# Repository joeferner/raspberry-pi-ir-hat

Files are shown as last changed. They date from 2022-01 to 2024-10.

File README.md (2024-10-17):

# Environment variables

- `LOG_LEVEL`
- `MQTT_ID` (default: `pi-ir`)
- `MQTT_HOST`
- `MQTT_PORT` (default: 1883)
- `MQTT_TOPIC_PREFIX` (default: `home/ir`)

# MQTT

- `${MQTT_TOPIC_PREFIX}/receive/raw` - raw IR data (see LircEvent)
- `${MQTT_TOPIC_PREFIX}/receive/decode` - decoded IR data (see DecodeResult)

# Setup Raspberry Pi

1. Install rpi-imager locally
1. Edit Settings
   - hostname: ir
   - set username/password
   - (optional) configure wireless lan
   - set locale settings
   - enable ssh
1. Start the Raspberry Pi, open a command prompt and `ping ir.local`
1. Open a terminal

        ssh <username>@ir.local
        sudo apt update
        sudo apt -y install git
        # copy id_rsa from host computer
        chmod 600 ~/.ssh/id_rsa
        ssh-keygen -p -f ~/.ssh/id_rsa # remove password
        git clone git@github.com:joeferner/raspberry-pi-ir-hat.git
        ./raspberry-pi-ir-hat/scripts/raspberry-pi-setup.sh

# Raspberry Pi development

1. Install "Remote Development" extension pack for VSCode.
1. Connect VSCode via ssh (Ctrl+Shift+P -> Remote-SSH: Connect to Host...) `<username>@ir.local`
1. Stop service `sudo systemctl stop raspberry-pi-ir-hat-network-bridge`
1. Run `RUST_BACKTRACE=1 LOG_LEVEL=debug cargo run`

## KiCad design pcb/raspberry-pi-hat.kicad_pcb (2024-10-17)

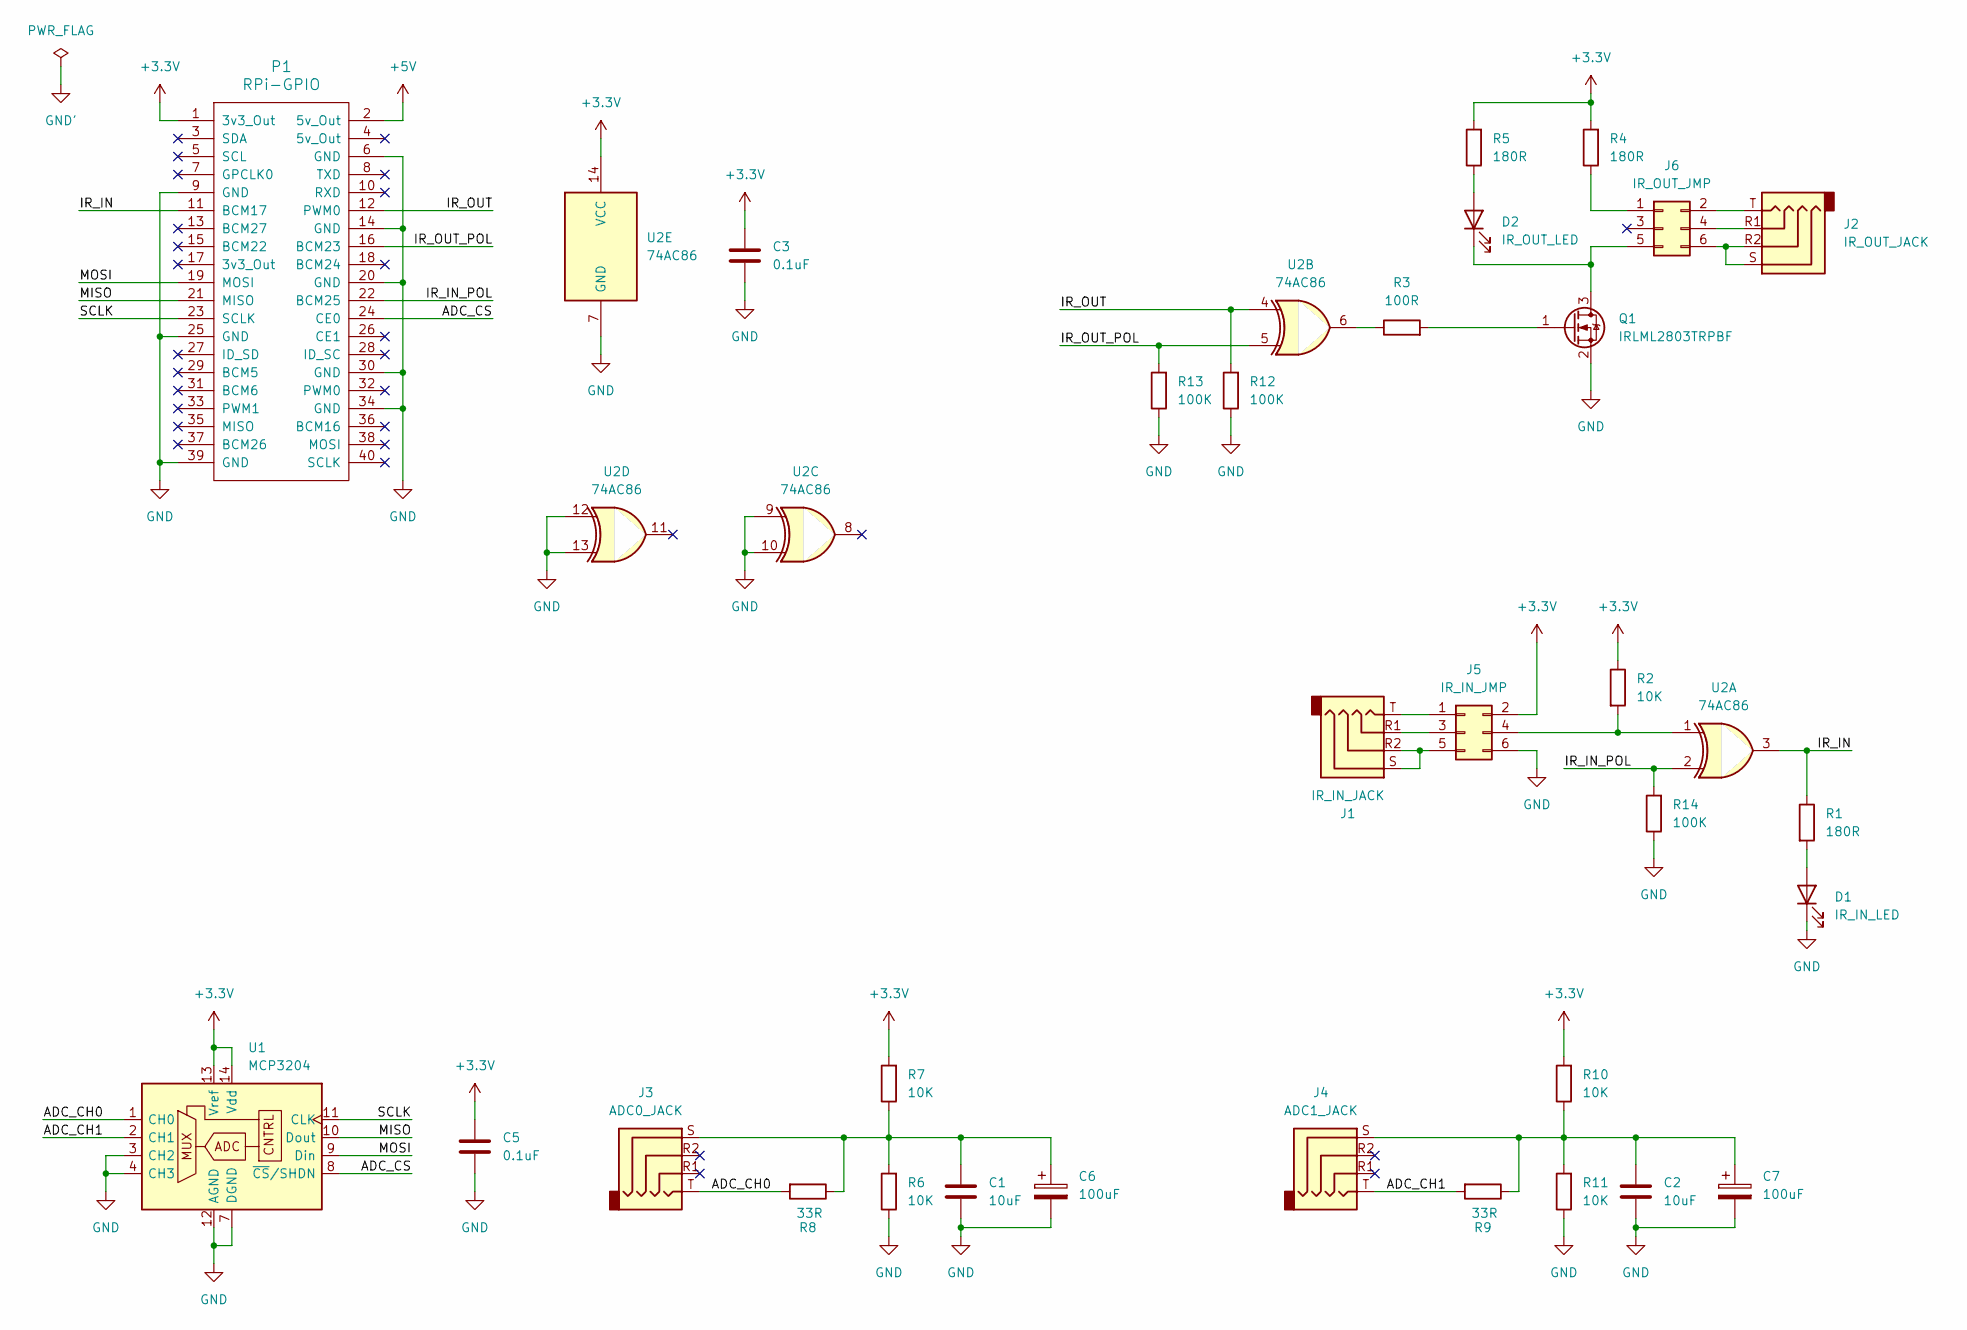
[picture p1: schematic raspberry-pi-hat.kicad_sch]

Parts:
C1, C2: 10uF; C_0805_2012Metric_Pad1.18x1.45mm_HandSolder
C3, C5: 0.1uF; C_0805_2012Metric_Pad1.18x1.45mm_HandSolder
C6, C7: 100uF; CP_Elec_5x5.3
D1: IR_IN_LED; LED_0805_2012Metric_Pad1.15x1.40mm_HandSolder
D2: IR_OUT_LED; LED_0805_2012Metric_Pad1.15x1.40mm_HandSolder
J1: IR_IN_JACK; 54-00174_TEN
J2: IR_OUT_JACK; 54-00174_TEN
J3: ADC0_JACK; 54-00174_TEN
J4: ADC1_JACK; 54-00174_TEN
J5: IR_IN_JMP; PinHeader_2x03_P2.54mm_Vertical
J6: IR_OUT_JMP; PinHeader_2x03_P2.54mm_Vertical
P1: RPi-GPIO; PinHeader_2x20_P2.54mm_Vertical
Q1: IRLML2803TRPBF; SOT-23
R1, R4, R5: 180R; R_0805_2012Metric_Pad1.20x1.40mm_HandSolder
R2, R6, R7, R10, R11: 10K; R_0805_2012Metric_Pad1.20x1.40mm_HandSolder
R3: 100R; R_0805_2012Metric_Pad1.20x1.40mm_HandSolder
R8, R9: 33R; R_0805_2012Metric_Pad1.20x1.40mm_HandSolder
R12, R13, R14: 100K; R_0805_2012Metric_Pad1.20x1.40mm_HandSolder
U1: MCP3204; SOIC-14_3.9x8.7mm_P1.27mm
U2: 74AC86; SOIC-14_3.9x8.7mm_P1.27mm

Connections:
+3.3V: C3.1, C5.1, J5.2, P1.1 (3v3_Out), R2.1, R4.2, R5.2, R7.2, R10.2, U1.13 (Vref), U1.14 (Vdd), U2.14 (VCC)
+5V: P1.2 (5v_Out)
/ADC_CH0: J3.T, R8.2, U1.1 (CH0)
/ADC_CH1: J4.T, R9.2, U1.2 (CH1)
/ADC_CS: P1.24 (CE0), U1.8 (~CS/SHDN)
/IR_IN: P1.11 (BCM17), R1.1, U2.3
/IR_IN_POL: P1.22 (BCM25), R14.2, U2.2
/IR_OUT: P1.12 (PWM0), R12.2, U2.4
/IR_OUT_POL: P1.16 (BCM23), R13.2, U2.5
/MISO: P1.21 (MISO), U1.10 (Dout)
/MOSI: P1.19 (MOSI), U1.9 (Din)
/SCLK: P1.23 (SCLK), U1.11 (CLK)
GND: C1.2, C2.2, C3.2, C5.2, C6.2, C7.2, D1.1 (K), J5.6, P1.6 (GND), P1.9 (GND), P1.14 (GND), P1.20 (GND), P1.25 (GND), P1.30 (GND), P1.34 (GND), P1.39 (GND), Q1.2 (S), R6.1, R11.1, R12.1, R13.1, R14.1, U1.3 (CH2), U1.4 (CH3), U1.7 (DGND), U1.12 (AGND), U2.7 (GND), U2.9, U2.10, U2.12, U2.13
unnamed: C1.1, C6.1, J3.S, R6.2, R7.1, R8.1
unnamed: C2.1, C7.1, J4.S, R9.1, R10.1, R11.2
unnamed: D1.2 (A), R1.2
unnamed: D2.2 (A), R5.1
unnamed: D2.1 (K), J6.5, Q1.3 (D)
unnamed: J1.T, J5.1
unnamed: J1.R1, J5.3
unnamed: J5.4, R2.2, U2.1
unnamed: J1.R2, J1.S, J5.5
unnamed: J6.1, R4.1
unnamed: J2.T, J6.2
unnamed: J2.R1, J6.4
unnamed: J2.R2, J2.S, J6.6
unnamed: Q1.1 (G), R3.2
unnamed: R3.1, U2.6

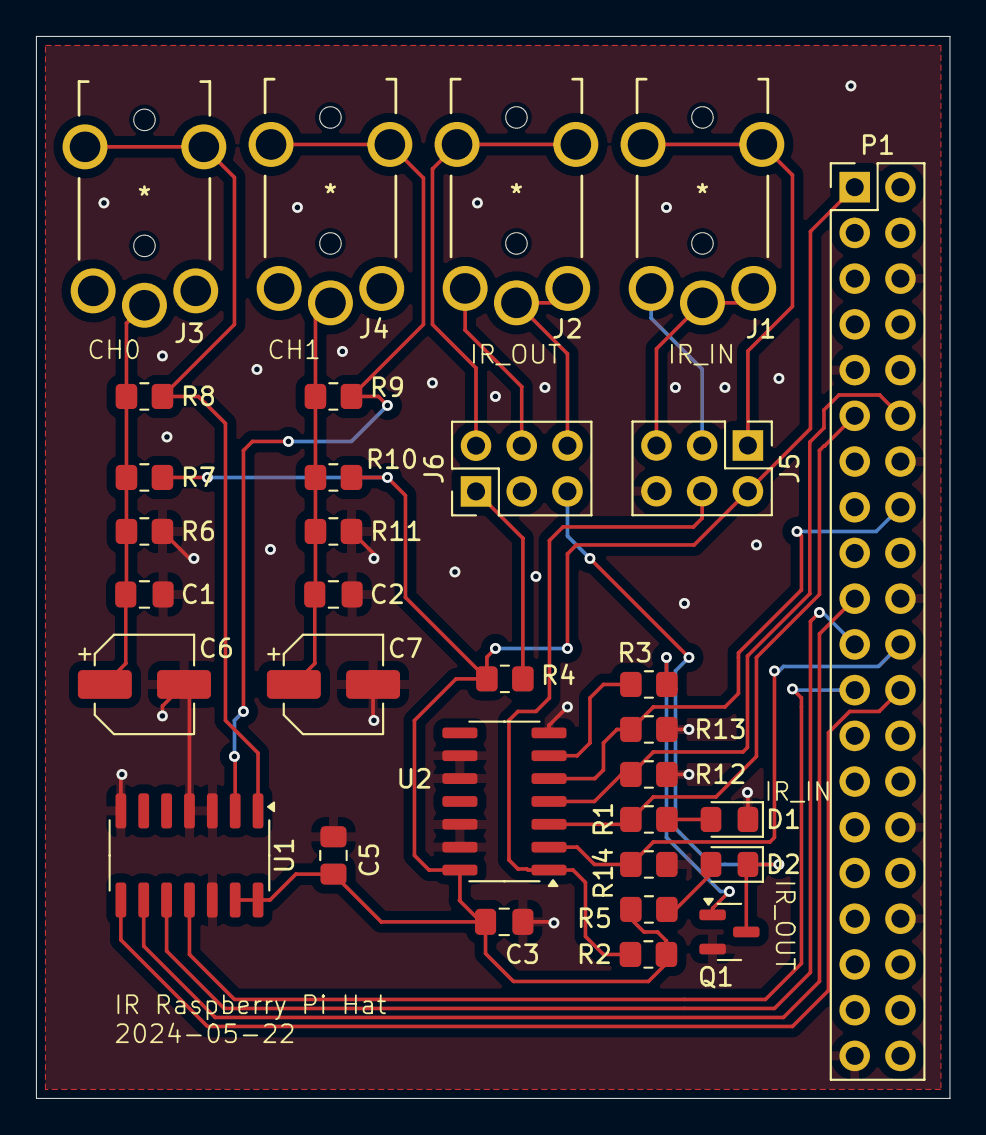
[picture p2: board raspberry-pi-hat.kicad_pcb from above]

Board: 2 copper layers, 50.8 x 59.0 mm, 32 parts (0 on the bottom side), 27 nets.

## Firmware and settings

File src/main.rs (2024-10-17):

use std::{process, time::Duration};

use anyhow::Result;
use config::Config;
use lirc::{find_lirc_devices, lirc_reader::LircReader, lirc_writer::LircWriter};
use log::{debug, error, info};
use remotes::{Key, Remotes};
use rumqttc::{AsyncClient, MqttOptions, QoS};
use serde::{Deserialize, Serialize};

mod config;
mod ioctl;
mod lirc;
mod logger;
mod rc_devices;
mod remotes;

#[tokio::main]
async fn main() -> Result<()> {
    let config = Config::new()?;
    info!("starting raspberry-pi-ir-hat-network-bridge");

    setup_ir_polarity()?;

    let lirc_devices = find_lirc_devices()?;
    log::debug!("lirc devices {:#?}", lirc_devices);

    let mut mqtt_options = MqttOptions::new(config.mqtt_id, config.mqtt_host, config.mqtt_port);
    mqtt_options.set_keep_alive(Duration::from_secs(5));

    let (mqtt_client, mut mqtt_event_loop) = AsyncClient::new(mqtt_options, 10);

    start_reader_loop(
        &lirc_devices.lirc_rx_device,
        &config.mqtt_topic_prefix,
        mqtt_client.clone(),
    )?;

    mqtt_client
        .subscribe(
            format!("{}/send/#", config.mqtt_topic_prefix),
            QoS::AtMostOnce,
        )
        .await?;

    debug!("starting main event loop");
    let mut state = State {
        lirc_writer: LircWriter::new(lirc_devices.lirc_tx_device)?,
        remotes: Remotes::new(),
    };
    loop {
        match mqtt_event_loop.poll().await {
            Ok(event) => handle_mqtt_event(event, &mut state)?,
            Err(e) => {
                error!("mqtt event loop poll failed; error = {e}");
                process::exit(1);
            }
        }
    }
}

fn handle_mqtt_event(event: rumqttc::Event, state: &mut State) -> Result<()> {
    match event {
        rumqttc::Event::Incoming(packet) => handle_mqtt_incoming_packet(packet, state),
        _ => Ok(()),
    }
}

fn handle_mqtt_incoming_packet(packet: rumqttc::Packet, state: &mut State) -> Result<()> {
    match packet {
        rumqttc::Packet::Publish(publish) => handle_mqtt_incoming_publish_packet(publish, state),
        _ => Ok(()),
    }
}

fn handle_mqtt_incoming_publish_packet(publish: rumqttc::Publish, state: &mut State) -> Result<()> {
    debug!("mqtt publish packet = {:?}", publish);
    if publish.topic.ends_with("/send/raw") {
        handle_mqtt_incoming_publish_packet_raw(publish, state)
    } else if publish.topic.ends_with("/send/encoded") {
        handle_mqtt_incoming_publish_packet_encoded(publish, state)
    } else {
        Ok(())
    }
}

fn handle_mqtt_incoming_publish_packet_raw(
    publish: rumqttc::Publish,
    state: &mut State,
) -> Result<()> {
    match serde_json::from_slice::<SendRaw>(&publish.payload) {
        Ok(send_raw) => {
            state
                .lirc_writer
                .write(send_raw.protocol, send_raw.scan_code)?;
        }
        Err(e) => {
            error!("failed to deserialize raw packet payload; error = {e}");
        }
    }
    Ok(())
}

fn handle_mqtt_incoming_publish_packet_encoded(
    publish: rumqttc::Publish,
    state: &mut State,
) -> Result<()> {
    match serde_json::from_slice::<SendEncoded>(&publish.payload) {
        Ok(send_encoded) => {
            let result = state.remotes.send(
                &mut state.lirc_writer,
                &send_encoded.remote_name,
                send_encoded.key,
            );
            if let Err(e) = result {
                error!("failed to send ir; error = {e}");
            }
        }
        Err(e) => {
            error!("failed to deserialize encoded packet payload; error = {e}");
        }
    }
    Ok(())
}

fn start_reader_loop(
    lirc_rx_device: &str,
    mqtt_topic_prefix: &str,
    mqtt_client: rumqttc::AsyncClient,
) -> Result<()> {
    async fn do_read(
        reader: &mut LircReader,
        mqtt_raw_receive_topic: &str,
        mqtt_decode_receive_topic: &str,
        mqtt_client: &rumqttc::AsyncClient,
        remotes: &mut Remotes,
    ) -> Result<()> {
        let lirc_events = reader.read()?;
        for lirc_event in lirc_events {
            debug!("recv ir event: {lirc_event:?}");
            let payload = serde_json::to_string(&lirc_event)?;
            mqtt_client
                .publish(mqtt_raw_receive_topic, QoS::AtMostOnce, false, payload)
                .await?;

            if let Some(decode_result) = remotes.decode(lirc_event) {
                log::debug!("decode_result {:?}", decode_result);
                let payload = serde_json::to_string(&decode_result)?;
                mqtt_client
                    .publish(mqtt_decode_receive_topic, QoS::AtMostOnce, false, payload)
                    .await?;
            }
        }
        Ok(())
    }

    let mut remotes = Remotes::new();
    let mut reader = LircReader::new(lirc_rx_device)?;
    let mqtt_raw_receive_topic = format!("{mqtt_topic_prefix}/receive/raw");
    let mqtt_decode_receive_topic = format!("{mqtt_topic_prefix}/receive/decode");
    tokio::spawn(async move {
        loop {
            do_read(
                &mut reader,
                &mqtt_raw_receive_topic,
                &mqtt_decode_receive_topic,
                &mqtt_client,
                &mut remotes,
            )
            .await
            .unwrap();
        }
    });
    Ok(())
}

fn setup_ir_polarity() -> Result<()> {
    let gpio = rppal::gpio::Gpio::new()?;

    let mut pin_ir_out_pol = gpio.get(23)?.into_output();
    let mut pin_ir_in_pol = gpio.get(25)?.into_output();
    pin_ir_out_pol.set_low();
    pin_ir_in_pol.set_low();

    Ok(())
}

struct State {
    lirc_writer: LircWriter,
    remotes: Remotes,
}

#[derive(Debug, Clone, Serialize, Deserialize)]
#[serde(rename_all = "camelCase")]
struct SendRaw {
    protocol: u16,
    scan_code: u64,
}

#[derive(Debug, Clone, Serialize, Deserialize)]
#[serde(rename_all = "camelCase")]
struct SendEncoded {
    remote_name: String,
    key: Key,
}

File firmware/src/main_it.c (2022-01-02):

#include "current_sensor.h"
#include "debug.h"
#include "ir_rx.h"
#include "ir_tx.h"
#include "main.h"
#include "rpi.h"
#include "time.h"

void NMI_Handler() {
}

void HardFault_Handler() {
  while (1)
    ;
}

void SVC_Handler() {
}

void PendSV_Handler() {
}

void SysTick_Handler() {
  time_increment_tick();
}

void DMA1_Channel1_IRQHandler() {
  ir_rx_irq();
}

void DMA1_Channel2_3_IRQHandler() {
  ir_rx_irq();
}

void DMA1_Channel4_5_6_7_IRQHandler() {
  ir_rx_irq();
}

void DMA1_Ch4_5_DMAMUX1_OVR_IRQHandler() {
  ir_rx_irq();
}

void TIM3_IRQHandler() {
  ir_rx_irq();
}

void TIM16_IRQHandler() {
  ir_tx_irq();
}

void WWDG_IRQHandler() {
  while (1)
    ;
}

void USART1_IRQHandler() {
  debug_usart_irq();
}

void USART2_IRQHandler() {
  rpi_usart_irq();
}

void TIM2_IRQHandler() {
  while (1)
    ;
}

void TIM1_CC_IRQHandler() {
  while (1)
    ;
}

void TIM1_BRK_UP_TRG_COM_IRQHandler() {
  while (1)
    ;
}

void ADC1_IRQHandler(void) {
  if (LL_ADC_IsActiveFlag_EOC(ADC1)) {
    LL_ADC_ClearFlag_EOC(ADC1);
    current_sensor_end_of_conversion();
  }

  if (LL_ADC_IsActiveFlag_EOS(ADC1)) {
    LL_ADC_ClearFlag_EOS(ADC1);
    current_sensor_end_of_sequence();
  }

  if (LL_ADC_IsActiveFlag_OVR(ADC1)) {
    LL_ADC_ClearFlag_OVR(ADC1);
    current_sensor_overrun_error();
  }
}

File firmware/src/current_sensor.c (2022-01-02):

#include "current_sensor.h"

#include <stdbool.h>
#include <stddef.h>
#include <stdlib.h>

#include "main.h"

#define VREF_mV (3300U)
#define VREF_DECAY 10
#define CURRENT_DECAY 10

/**
 * Number of samples to take before adding the max value to current results
 */
#define LOCAL_SEQUENCE_COUNT 50
#define MAX(x, y) (((x) > (y)) ? (x) : (y))

typedef enum
{
  CurrentReadRank_Reference,
  CurrentReadRank_Current1,
  CurrentReadRank_Current0,
  CurrentReadRank_Unknown,
} CurrentReadRank;

static uint16_t current_reference_mV;
static uint16_t current_0_mV;
static uint16_t current_0_local_max_mV;
static uint16_t current_1_mV;
static uint16_t current_1_local_max_mV;
static uint16_t sequence_count;
static CurrentReadRank current_read_rank;
static volatile bool end_of_conversion;
static volatile bool end_of_sequence;

static uint16_t to_mA(uint16_t mV);

void current_sensor_setup() {
  end_of_conversion = false;
  end_of_sequence = false;
  current_0_mV = current_1_mV = current_reference_mV = 3300 / 2;
  current_0_local_max_mV = current_1_local_max_mV = 0;
  sequence_count = 0;
  current_read_rank = CurrentReadRank_Current1;  // CurrentReadRank_Reference
  LL_ADC_EnableIT_EOC(ADC1);
  LL_ADC_EnableIT_EOS(ADC1);
  LL_ADC_EnableIT_OVR(ADC1);
  LL_ADC_Enable(ADC1);
  LL_ADC_REG_StartConversion(ADC1);
}

void current_sensor_loop() {
  bool start_conversion = false;

  if (end_of_conversion) {
    uint16_t raw_data = LL_ADC_REG_ReadConversionData12(ADC1);
    uint32_t data_mV = __LL_ADC_CALC_DATA_TO_VOLTAGE(VREF_mV, raw_data, LL_ADC_RESOLUTION_12B);

    if (current_read_rank == CurrentReadRank_Reference) {
      current_reference_mV = ((VREF_DECAY * data_mV) + ((100 - VREF_DECAY) * current_reference_mV)) / 100;
      current_read_rank = CurrentReadRank_Current0;
    } else if (current_read_rank == CurrentReadRank_Current0 || current_read_rank == CurrentReadRank_Current1) {
      uint16_t diff = abs((int32_t)current_reference_mV - (int32_t)data_mV);

      if (current_read_rank == CurrentReadRank_Current0) {
        current_0_local_max_mV = MAX(diff, current_0_local_max_mV);
        current_read_rank = CurrentReadRank_Unknown;  // TODO CurrentReadRank_Current1
      } else if (current_read_rank == CurrentReadRank_Current1) {
        current_1_local_max_mV = MAX(diff, current_1_local_max_mV);
        current_read_rank = CurrentReadRank_Reference;  // TODO CurrentReadRank_Unknown
      } else {
        assert_param(false);
      }
    }

    end_of_conversion = false;
    start_conversion = true;
  }

  if (end_of_sequence) {
    current_read_rank = CurrentReadRank_Current1;  // TODO CurrentReadRank_Reference
    end_of_sequence = false;
    sequence_count++;
    if (sequence_count > LOCAL_SEQUENCE_COUNT) {
      current_0_mV = ((CURRENT_DECAY * current_0_local_max_mV) + ((100 - CURRENT_DECAY) * current_0_mV)) / 100;
      current_0_local_max_mV = 0;
      current_1_mV = ((CURRENT_DECAY * current_1_local_max_mV) + ((100 - CURRENT_DECAY) * current_1_mV)) / 100;
      current_1_local_max_mV = 0;
      sequence_count = 0;
    }
  }

  if (start_conversion) {
    LL_ADC_REG_StartConversion(ADC1);
  }
}

void current_sensor_end_of_conversion() {
  end_of_conversion = true;
}

void current_sensor_end_of_sequence() {
  end_of_sequence = true;
}

uint16_t current_sensor_get_ref() {
  return current_reference_mV;
}

uint16_t current_sensor_get0() {
  return to_mA(current_0_mV);
}

uint16_t current_sensor_get1() {
  return to_mA(current_1_mV);
}

static uint16_t to_mA(uint16_t mV) {
  uint32_t data = MAX(0, mV - 15);
  return (data * 890) / 1000;
}

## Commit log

2020-09-11 fix drc
    [raspberry-pi-ir-hat.kicad_pcb]
2020-09-23 add labels
    [raspberry-pi-ir-hat.kicad_pcb]
2020-09-29 Flip hat to outside
    [raspberry-pi-ir-hat.kicad_pcb, raspberry-pi-ir-hat.sch]
2020-10-01 cutout for ethernet port
    [raspberry-pi-ir-hat-B_Cu.gbl, raspberry-pi-ir-hat-B_Mask.gbs, raspberry-pi-ir-hat-B_SilkS.gbo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]
2020-10-21 update pcb
    [raspberry-pi-ir-hat.kicad_pcb, raspberry-pi-ir-hat.sch]
2020-10-27 add stm32 to pcb
    [raspberry-pi-ir-hat.kicad_pcb, raspberry-pi-ir-hat.sch]
2020-10-28 update schematic and pcb with mcu
    [raspberry-pi-ir-hat.kicad_pcb, raspberry-pi-ir-hat.sch]
2020-10-30 update pcbs
    [raspberry-pi-ir-hat-B_Cu.gbl, raspberry-pi-ir-hat-B_Mask.gbs, raspberry-pi-ir-hat-B_SilkS.gbo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]
2020-10-31 calibrate rx and enable systick
2020-11-23 switch to stm32g0
    [stm32g0x.cfg]
2020-11-24 working ir in/out
    [raspberry-pi-ir-hat.kicad_pcb]
2020-11-25 remove models
    [Assem1^Raspberry Pi 3.iam, Board_Geoms_1d0a.iam, C1_C_0805_2012Metric_5F7375B8.ipt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]
2020-11-29 change debug to using dma ring buffer
2021-08-28 dma fix
2021-08-29 switch to iwdg
2021-10-13 export ButtonPress
2021-10-24 current sense
    [raspberry-pi-ir-hat.sch]
2021-10-24 untested adc
    [raspberry-pi-ir-hat.sch]
2021-10-25 more current sensor
2021-10-28 current reading working
2021-10-28 add command to get current
2021-10-30 get current
2021-11-06 switch to yaml
2022-01-03 switch to cmake
2022-01-09 denon ir decoding
    [num1.csv, num2.csv, power-off.csv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]
2022-01-10 print ir results
2022-01-17 working read of denon and NEC
    [power.csv, volume-down.csv, volume-up.csv]
2022-01-23 print time since last signal
2022-01-29 working driver
2022-02-06 remove nodejs driver
2022-02-19 switch to mpsc instead of callback
2022-04-07 start of node driver
2024-10-16 new pcb
    [HDMI-Female-PanelMount.0005.iam, Micro USB Plug.0001.iam, USB-TypeB-Female-PanelMount.0003.iam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]
2024-10-16 remove old firmware
    [HDMI-Female-PanelMount.0005.iam, Micro USB Plug.0001.iam, USB-TypeB-Female-PanelMount.0003.iam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]
